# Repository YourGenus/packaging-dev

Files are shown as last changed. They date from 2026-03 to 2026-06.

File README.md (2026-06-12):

# Genus Packaging Development

Genus is the next‑generation consumer brand.  
We are currently prototyping sustainable‑by‑design packaging systems, exploring modular forms using **Aluminum** and **PCR** as core materials, and building a modern platform for rapid iteration.  
We are engineering the identity‑driven future.

---

## Purpose

This repository contains early explorations, prototypes, and schema foundations for the Genus packaging system, including:

- Modular packaging architecture  
- Aluminum + PCR hybrid components  
- Parametric and code‑driven design  
- Genre‑based identity systems  
- Rapid iteration workflows using modern tools and AI  

---

## Core Schema

The Genus Core Schema defines the building blocks of the system:

- **Genres** — identity frameworks (Citizen, Athlete, Dreamer, Metropolitan, Traveler)  
- **Product Categories** — cleanser, mist, serum  
- **Types** — standard, extended, compact, insert‑only  
- **Parts** — shell, insert, cap  

These components form the foundation for future automation, 3D generation, and product configuration.

---

## Materials

Genus focuses on circular, sustainable materials:

- **Aluminum** — durable, infinitely recyclable  
- **PCR (Post‑Consumer Recycled plastics)** — lightweight, responsible, refill‑friendly  

---

## License

CC0‑1.0 — Public Domain

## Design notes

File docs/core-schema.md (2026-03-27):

# Genus Core Schema v0.1  
Foundational design architecture for genres, product categories, types, parts, and parameters.  
---

## 1. Purpose  
This schema defines the core building blocks of the Genus design system. It provides a unified structure for:

- Design guidelines  
- Product architecture  
- Variant generation  
- Future supply‑chain and operations data  
- Automated product configuration  

This document is versioned and will evolve as the platform grows.

---

## 2. Genres  
Identities that influence color, tone, and emotional expression across the Genus ecosystem.

Each genre includes:  
- **id**: unique key  
- **name**: human-readable name  
- **tags**: emotional or functional associations  
- **colors**: primary, secondary, accent  

### 2.1 Genre Schema  
```json
{
  "id": "string",
  "name": "string",
  "tags": ["string"],
  "colors": {
    "primary": "hex",
    "secondary": "hex",
    "accent": "hex"
  }
}
```

### 2.2 Current Genres  
(Directly from the JSON source)

- Citizen  
- Athlete  
- Dreamer  
- Metropolitan  
- Traveler  

---

## 3. Product Categories  
High-level functional groupings that define the purpose of a product.

Each category includes:  
- **id**: unique key  
- **name**: category name  
- **description**: functional definition  

### 3.1 Product Category Schema  
```json
{
  "id": "string",
  "name": "string",
  "description": "string"
}
```

### 3.2 Current Product Categories  
- Cleanser  
- Mist  
- Serum  

---

## 4. Types  
Form factors that define physical dimensions, volume, and required parts.

Each type includes:  
- **id**: unique key  
- **name**: type name  
- **description**: purpose or usage context  
- **parameters**: measurable attributes (volume, height, diameter)  
- **parts**: list of required components  

### 4.1 Type Schema  
```json
{
  "id": "string",
  "name": "string",
  "description": "string",
  "parameters": {
    "volume": "number (optional)",
    "height": "number",
    "diameter": "number"
  },
  "parts": ["string"]
}
```

### 4.2 Current Types  
- Standard  
- Extended  
- Compact  
- Insert Only  

---

## 5. Parts  
Physical components used across types.  
Parts are modular and reusable across product types.

Each part includes:  
- **id**: unique key  
- **name**: part name  
- **material**: e.g., PCR, PP, PET  
- **finish**: matte, gloss, soft-touch  
- **colorMode**:  
  - `"genre"` → inherits from genre colors  
  - `"fixed"` → uses a defined color  
- **dimensions** (optional): height, diameter, wall thickness  

### 5.1 Part Schema  
```json
{
  "id": "string",
  "name": "string",
  "material": "string",
  "finish": "string",
  "colorMode": "genre | fixed",
  "color": "hex (optional)",
  "dimensions": {
    "height": "number (optional)",
    "diameter": "number (optional)",
    "thickness": "number (optional)"
  }
}
```

### 5.2 Example Parts  
```json
{
  "parts": [
    {
      "id": "shell",
      "name": "Outer Shell",
      "material": "ABS",
      "finish": "matte",
      "colorMode": "genre"
    },
    {
      "id": "insert",
      "name": "PCR Insert",
      "material": "PCR",
      "finish": "semi-gloss",
      "colorMode": "fixed",
      "color": "#F5F5F5"
    },
    {
      "id": "cap",
      "name": "Cap",
      "material": "PP",
      "finish": "matte",
      "colorMode": "genre"
    }
  ]
}
```

---

## 6. Parameters  
Quantitative attributes used for product configuration, manufacturing, and variant generation.

### 6.1 Parameter Types  
- **volume** (ml)  
- **height** (mm)  
- **diameter** (mm)  
- **weight** (g)  
- **threadType** (e.g., 24/410)  
- **compatibility** (list of compatible parts or types)  

### 6.2 Parameter Schema  
```json
{
  "name": "string",
  "unit": "string",
  "value": "number",
  "tolerance": "number (optional)"
}
```

---

## 7. Product Definition  
A product is generated by combining:  
- **genre**  
- **productCategory**  
- **type**  
- **parts**  
- **parameters**  

This enables automated variant generation and future supply-chain integration.

### 7.1 Product Schema  
```json
{
  "id": "string",
  "genre": "genre.id",
  "category": "productCategory.id",
  "type": "type.id",
  "parts": ["part.id"],
  "parameters": {
    "volume": "number",
    "height": "number",
    "diameter": "number"
  }
}
```

---

## 8. Variant Generation Rules  
The system can automatically generate product variants using:

### 8.1 Genre-Based Rules  
- Shell and cap inherit **genre colors**  
- Accent color may apply to:  
  - logo  
  - ring detail  
  - cap band  

### 8.2 Type-Based Rules  
- Dimensions and volume come from the type  
- Parts required by the type must be present  

### 8.3 Category-Based Rules  
- Cleanser → pump or flip-cap  
- Mist → spray actuator  
- Serum → dropper or precision pump  

### 8.4 Compatibility Rules  
- Insert must match shell diameter  
- Cap must match thread type  
- Volume must not exceed insert capacity  

---

## 9. Future Extensions  
Planned schema expansions:

- **Bill of Materials (BOM)**  
- **Manufacturing metadata**  
- **SKU-level supply chain attributes**  
- **Regulatory compliance fields**  
- **Localization (languages, markets)**  
- **Sustainability scoring**  

---

## 10. Versioning  
This schema follows semantic versioning:  
- **0.x** → experimental  
- **1.0** → stable release  
- **1.x** → incremental improvements

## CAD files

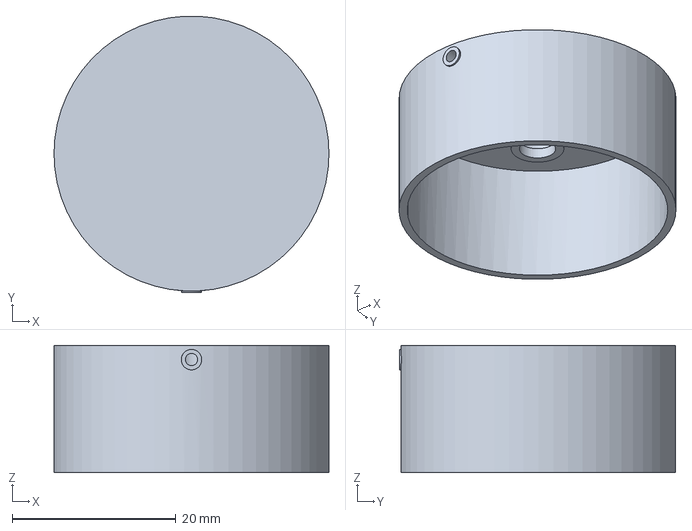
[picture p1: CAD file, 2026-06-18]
parts/actuator/gen-pc1_actuator.FCStd
33.6 x 33.8 x 15.6 mm

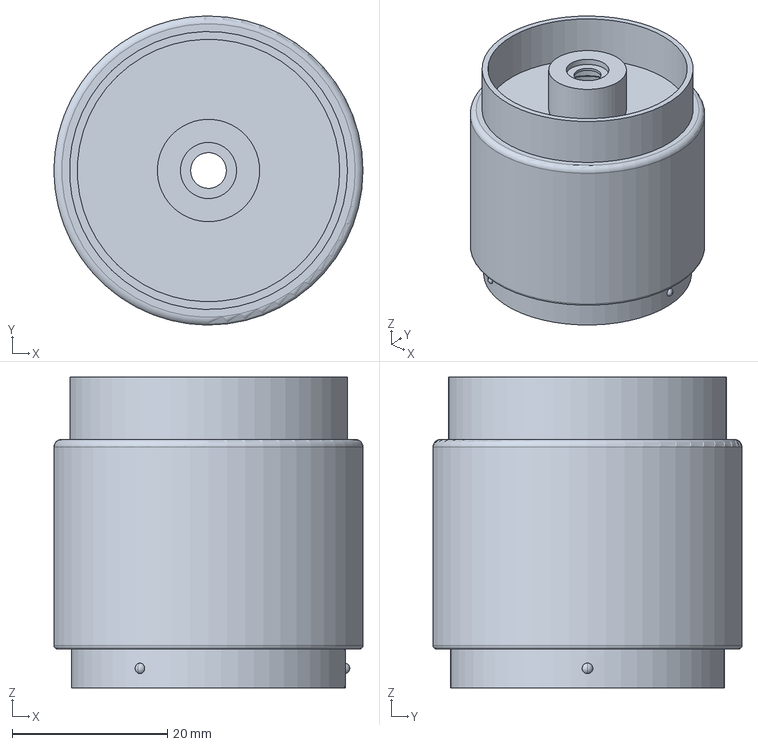
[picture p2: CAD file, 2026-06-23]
parts/body/gen-pc1_body_v0.1.2.FCStd
39.8 x 39.8 x 40.0 mm

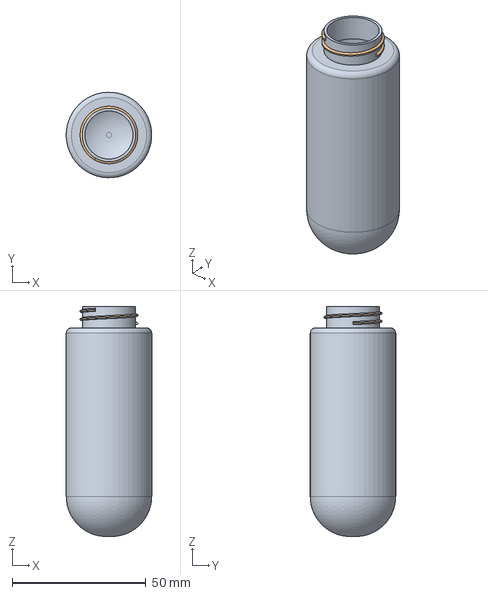
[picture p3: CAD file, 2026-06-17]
parts/insert/gen-pc1_insert.FCStd
32.0 x 32.0 x 86.0 mm
Insert
Thread001

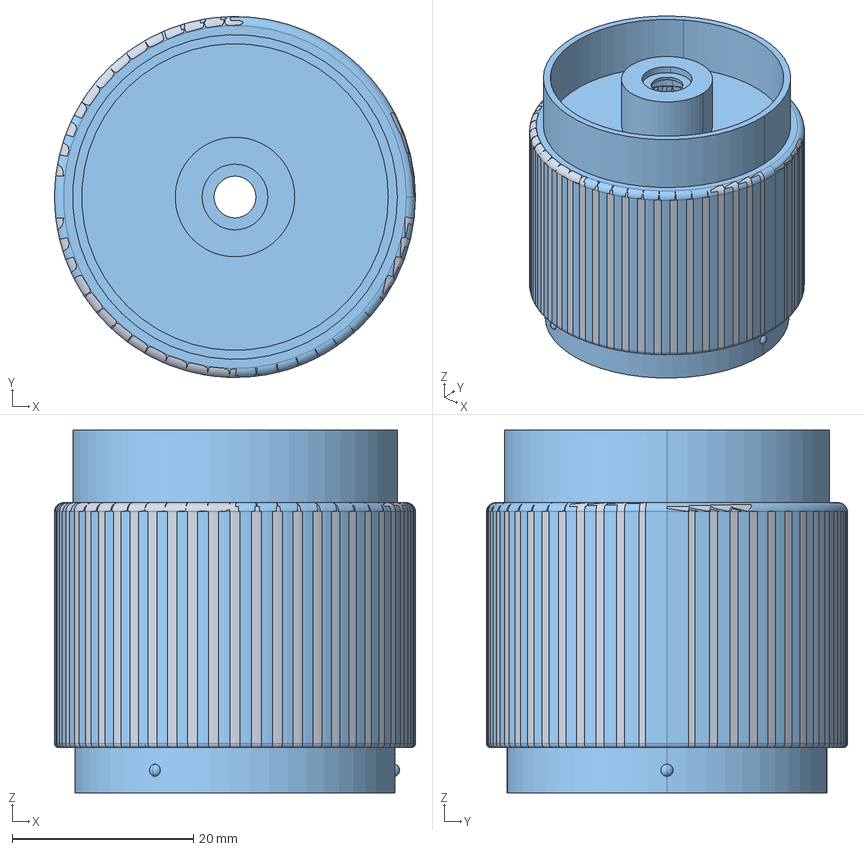
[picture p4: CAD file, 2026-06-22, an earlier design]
parts/body/gen-pc1_body_v0.1.1.FCStd
39.8 x 39.8 x 40.0 mm
Thread

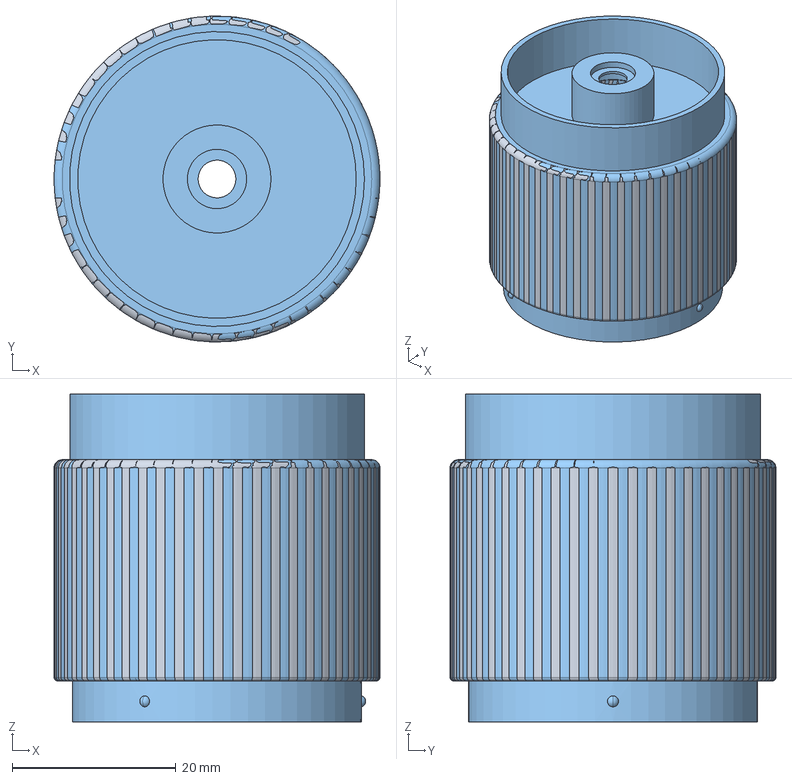
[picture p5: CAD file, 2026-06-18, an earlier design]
parts/body/gen-pc1_body.FCStd
39.8 x 39.8 x 40.0 mm
Thread
Detents

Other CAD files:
parts/actuator/gen-pc1_actuator.stl
parts/body/gen-pc1_body.stl
parts/body/gen-pc1_body_v0.1.1.stl
parts/body/gen-pc1_body_v0.1.2.stl
parts/insert/gen-pc1_insert.stl

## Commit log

2026-03-27 feat: schema-driven p5 renderer with JSON loading, dynamic type scaling, and material-based color logic
2026-03-27 feat: UI and material loading logic update
2026-03-27 feat(rendering): implement 3‑part insert assembly with correct visibility rules
2026-03-27 fix(rendering): center all parts relative to shell diameter - Added universal centering logic for all components - Insert-body neck + body now centered - Dispenser and cartridge centered in insert-on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
2026-04-01 feat(3d-viewer): fix param merging, align part schemas, and correct model stacking Details: - Replaced debug param structure with proper merged params in useProductState - Standardized part IDs (shel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
    If you want, I can also generate:
    - a shorter version
    - a more formal conventional‑commit style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
2026-04-01 fix(3d-viewer): correct part stacking, remove legacy offsets, and restore shell/pump/cap visibility Details: - Replaced outdated offset usage in Cap and Pump components - Updated Shell to use radius 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
2026-04-02 feat: mesh update with satin option, lightining and camera adjustments
2026-04-02 fix: Adjust lighting and camera for improved 3D visualization
2026-04-14 Improve 3D product scene: fix shadows, lighting, and studio environment - Enabled proper shadow casting for all product meshes - Added automatic mesh traversal in ProductModel to set castShadow/recei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
2026-04-14 Lighning and environment adjustments for better material visibility and contrast.
2026-04-14 Orbit adjustments for better product visibility, reduced ambient light intensity for improved contrast, and slightly less intense key and rim lights to create a more balanced and visually appealing s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
2026-06-12 Revise README for Genus packaging development
    Refined the project’s README and GitHub About text to better communicate Genus’ mission and current development focus. Updated language to clearly describe the sustainable‑by‑design packaging prototy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
2026-06-16 actuator v0.1.3 – chamber diameter + height update
    [gen-pc1_actuator.FCStd, gen-pc1_actuator.stl]
2026-06-16 - Internal diameter of Valve Stem Chamber increased to 4.4 mm - Total actuator height set to 15.56 mm - Added updated FreeCAD file and STL export
2026-06-17 Gen-pc1 - Initial Body and Insert files added
    [gen-pc1_body.FCStd, gen-pc1_body.stl, gen-pc1_insert.FCStd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]
2026-06-17 Fix: Actuator .stl file reuploaded
    [gen-pc1_actuator.stl]
2026-06-18 actuator v0.1.5 - Improved inner socket stability
    Reduced material thickness above the actuator chamber (above the valve stem) to 1 mm. This lowers the mass above the stem interface and reduces the effective height from the valve stem top to the actuator top, improving stability and minimizing tilting during actuation.
    [gen-pc1_actuator.FCStd]
2026-06-18 body v0.1.0: shroud height and versioning update
    Set body shroud wall height to 8 mm to conceal actuator outer wall.
    Assign the Body version.
    [gen-pc1_body.stl]
2026-06-19 Updated fitting with Pump and Actuator + export fix
    - Increased the Pump mounting collar diameter to reduce force for Pump assembly.
    - Decreased shroud diameter to fit the Actuator
    - Merged the thread to the Body part
    [gen-pc1_body_v0.1.1.stl]
2026-06-22 Refactor folder structure for improved readability and maintainability
    [gen-pc1_actuator.FCStd, gen-pc1_actuator.stl, gen-pc1_body.FCStd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]
2026-06-22 Decreased Retention Taper diameter
    Decreased Retention Taper diameter to prevents unintended downward movement of the pump during actuator assembly.
    Upload body_v0.1.2 files.
    [gen-pc1_body_v0.1.2.FCStd, gen-pc1_body_v0.1.2.stl]
2026-06-23 body_v0.1.2 - Fix the CAD tree structure
    Fixed thread duplication. Fixed pattern duplication.
    Refactored CAD structure:
    - separated bodies
    - corrected polar pattern usage
    - improved parametric stability
    [gen-pc1_body_v0.1.2.FCStd, gen-pc1_body_v0.1.2.stl]
2026-08-13 Initial DFM-compliant Body part files
    Initial part files designed for injection molding constraints.
    [gen-pc1_body_c_v0.1-Body.stl, gen-pc1_body_c_v0.1.FCStd]
2026-10-15 Body optimized for better fit and material usage
    - Outer Snap-fit Neck diameter reduced to 35.00 mm to better fit the Shell.
    - Snap-fit Neck wall thickness reduced to 0.70 mm (main wall thickness reduced in the same time) to reduce the material usage.
    - Detents radius reduced to 0.60 mm for softer snap-fit the Shell.
    - Detents center positioned at 17.40 mm (X-axis) for softer snap-fit the Shell.
2026-10-16 Actuator initial design prepared for MBU unit
    Initial design prepared for MBU unit tests.
2026-10-19 Actuator geometry optimized and naming update.
    Terminological Update: Renamed MBU Housing to Insert Pocket across all design documents and CAD feature trees.
    Stem Valve Interface: Increased the Stem Valve (Pump Engine Interface) diameter to 4.00 mm.
    Insert Pocket Profile: Adjusted the Insert Pocket Shoulder diameters to 4.10 mm (Front) and 3.90 mm (Back).
    Locking Feature: Increased the Insert Pocket Locking Ring Groove length to 0.70 mm.
    Swirl Pin length set to 3.50 mm.
    Steam Stop position set.
2026-10-21 Refine nozzle interface geometry and internal flow path
    actuator_v0.2.8
    Pocket Shoulder Front diameter increased to 4.20 mm, Back diameter increased to 4.00 mm.
    Locking Ring Groove diameter position moved from -2.80 to -2.70 in z axis.
    Swirl Pin position moved to -1.70 mm in z axis, resulting in 1.00 mm difference between Nozzle Insert Face and Swirl Pin Face.
    Horizontal Feed Channel positioned to Expansion Chamber level. Stem Socket Sump length increased to 2.70 mm.
